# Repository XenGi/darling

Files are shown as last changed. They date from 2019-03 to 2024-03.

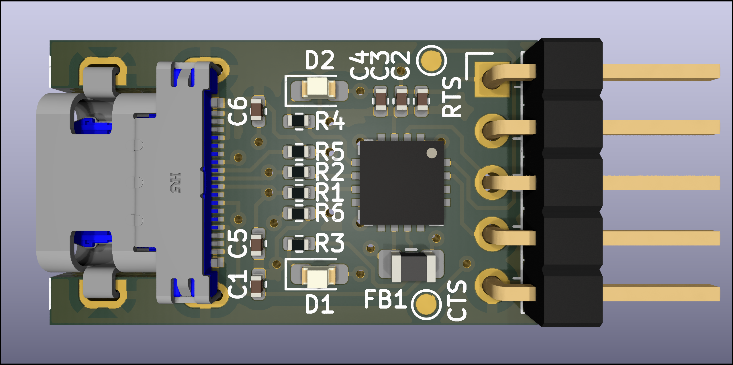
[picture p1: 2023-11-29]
darling_3d_front.png

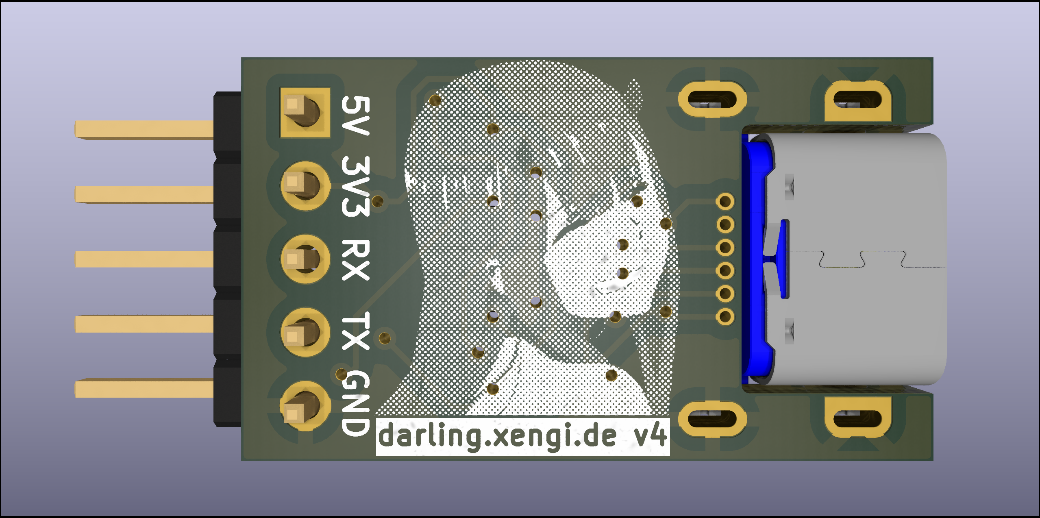
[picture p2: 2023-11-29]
darling_3d_back.png

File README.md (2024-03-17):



pcb
3d model front
3d model back

darling
=======

FTDI helper for the future. With FT230X, blinky lights and USB-C! Also potentially the tinyest USB-C to Serial adapter in the world. :smiley:

__Got a smaller USB-C to serial adapter? Please send me a link!__

BOM
---

| Part | Qty | Pkg | Ref | Description | Mouser | LCSC |
| --- | - | ----- | --- | --- | --- | ---- |
| Hirose CX70M-24P1 | 1 | - | J1 | USB-C Receptacle  | [798-CX70M-24P1](https://eu.mouser.com/ProductDetail/Hirose-Connector/CX70M-24P1?qs=NniTrqY%252BJ%252BUR9QssvRGPwA%3D%3D) | [C778726](https://www.lcsc.com/product-detail/C778726.html) |
| - | 1 | - | J2 | Pin Header | [571-826947-5](https://eu.mouser.com/ProductDetail/TE-Connectivity/826947-5?qs=xF5SkmKSM76JMcUnQ8djKQ%3D%3D) | [C6332198](https://www.lcsc.com/product-detail/C6332198) |
| FTDI FT230XQ-R | 1 | QFN16 | U1 | USB-Serial IC | [895-FT230XQ-R](https://eu.mouser.com/ProductDetail/FTDI/FT230XQ-R?qs=Gp1Yz1mis3VvmXwyDmIHOg%3D%3D) | [C128629](https://www.lcsc.com/product-detail/C128629) |
| - | 1 | 0603  | D1 | Red RX LED | [710-150060GS75000](https://eu.mouser.com/ProductDetail/Wurth-Elektronik/150060GS75000?qs=LlUlMxKIyB0UYkq5lDO8nA%3D%3D) | [C965804](https://www.lcsc.com/product-detail/C965804) |
| - | 1 | 0603  | D2 | Green TX LED | [710-150060RS75000](https://eu.mouser.com/ProductDetail/Wurth-Elektronik/150060RS75000?qs=LlUlMxKIyB3QnmZ3fw%2FVCA%3D%3D) | [C965799](https://www.lcsc.com/product-detail/C965799) |
| - | 2 | 0402  | R1, R2 | 27 Ohm Resistor | [652-CR0402FX-27R0GLF](https://eu.mouser.com/ProductDetail/Bourns/CR0402-FX-27R0GLF?qs=SFHnMgm9IsxG%252BvpJZf0h2g%3D%3D) | [C138021](https://www.lcsc.com/product-detail/C138021) |
| - | 2 | 0402  | R3, R4 | 270 Ohm Resistor  | [652-CR0402FX-2700GLF](https://eu.mouser.com/ProductDetail/Bourns/CR0402-FX-2700GLF?qs=SFHnMgm9IsyXrY3JqhOnHQ%3D%3D) | [C163474](https://www.lcsc.com/product-detail/C163474) |
| - | 2 | 0402  | R5, R6 | 5.1 kOhm Resistor | [652-CR0402FX-5101GLF](https://eu.mouser.com/ProductDetail/Bourns/CR0402-FX-5101GLF?qs=ePR1ZvdkOKImkuXR%2F%2FtvtA%3D%3D) | [C105873](https://www.lcsc.com/product-detail/C105873) |
| - | 1 | 0402  | C1 | 10 nF Capacitor | [80-C0402C103K3R7867](https://eu.mouser.com/ProductDetail/KEMET/C0402C103K3RAC7867?qs=2QcrrtqkWlmbWpEppaNgjw%3D%3D) | [C272878](https://www.lcsc.com/product-detail/C272878) |
| - | 2 | 0402  | C2, C4 | 100 nF Capacitor  | [81-GRM155C71H104JE9J](https://eu.mouser.com/ProductDetail/Murata-Electronics/GRM155C71H104JE19J?qs=QzBtWTOodeUR0Y4f0k0Zww%3D%3D) | [C541464](https://www.lcsc.com/product-detail/C541464) |
| - | 1 | 0402  | C3 | 4.7 uF Capacitor  | [81-GRM15C61E475ME15J](https://eu.mouser.com/ProductDetail/Murata-Electronics/GRM155C61E475ME15J?qs=By6Nw2ByBD02p8xq06vhEQ%3D%3D) | [C368809](https://www.lcsc.com/product-detail/C368809) |
| - | 2 | 0402  | C5, C6 | 47 pF Capacitor | [81-GRT1555C1H470FA2D](https://eu.mouser.com/ProductDetail/Murata-Electronics/GRT1555C1H470FA02D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) | [C527009](https://www.lcsc.com/product-detail/C527009) |
| Laird MI0805K601R-10 | 1 | 0805  | FB1 | Ferrite Bead | [875-MI0805K601R-10](https://eu.mouser.com/ProductDetail/Laird-Performance-Materials/MI0805K601R-10?qs=bbdZqDPQhEXXIHxc191aOg%3D%3D) | [C21286](https://www.lcsc.com/product-detail/C21286) |

See [Octopart][octopart] for a detailed list with links.
With current prices this totals to ~4.50€ just for parts excluding costs for the PCB manufacturing. If you need a PCB, just ask. I have lots of them. :)

Schematics
----------

schematics

Create Gerber files
-------------------

Export the gerber and drill files from KiCAD to a subdir like `gerber`. To create a ZIP file with the needed gerber files for a PCB fab:

```
cd gerber
zip darling.zip *.gbr *.drl
```

I recommend [JLCPCB][jlcpcb]. It's the cheapest way to get the PCBs and they offer decent quality.
You can directly order it at [PCBWay][pcbway]. They've got some nice matte black PCBs!
If you want purple PCBs you can also use [OSHPark][oshpark].
If you want it faster and you're in Germany/EU I uploaded it to [Aisler][aisler] to.

[pcb top pcb bottom][oshpark]

---

_Made with :heart: and aliexpress_

[pcb]: https://gitlab.com/xengi/darling/raw/master/darling_pcb.png
[3d-front]: https://gitlab.com/xengi/darling/raw/master/darling_3d_front.png
[3d-back]: https://gitlab.com/xengi/darling/raw/master/darling_3d_back.png
[schema]: https://gitlab.com/xengi/darling/raw/master/darling_schema.png
[octopart]: https://octopart.com/bom-tool/4VikRkAe
[jlcpcb]: https://jlcpcb.com/
[pcbway]: https://www.pcbway.com/project/shareproject/Darling_Rev4_f9889cb6.html
[oshpark_darling_top]: https://644db4de3505c40a0444-327723bce298e3ff5813fb42baeefbaa.ssl.cf1.rackcdn.com/4cf1ffcfeee0332e9eda92195310da6b.png
[oshpark_darling_bottom]: https://644db4de3505c40a0444-327723bce298e3ff5813fb42baeefbaa.ssl.cf1.rackcdn.com/1f266f38a687f960f46bc39729592b03.png
[oshpark]: https://oshpark.com/shared_projects/s8UnAcGC
[aisler]: https://aisler.net/p/NFTQABKA

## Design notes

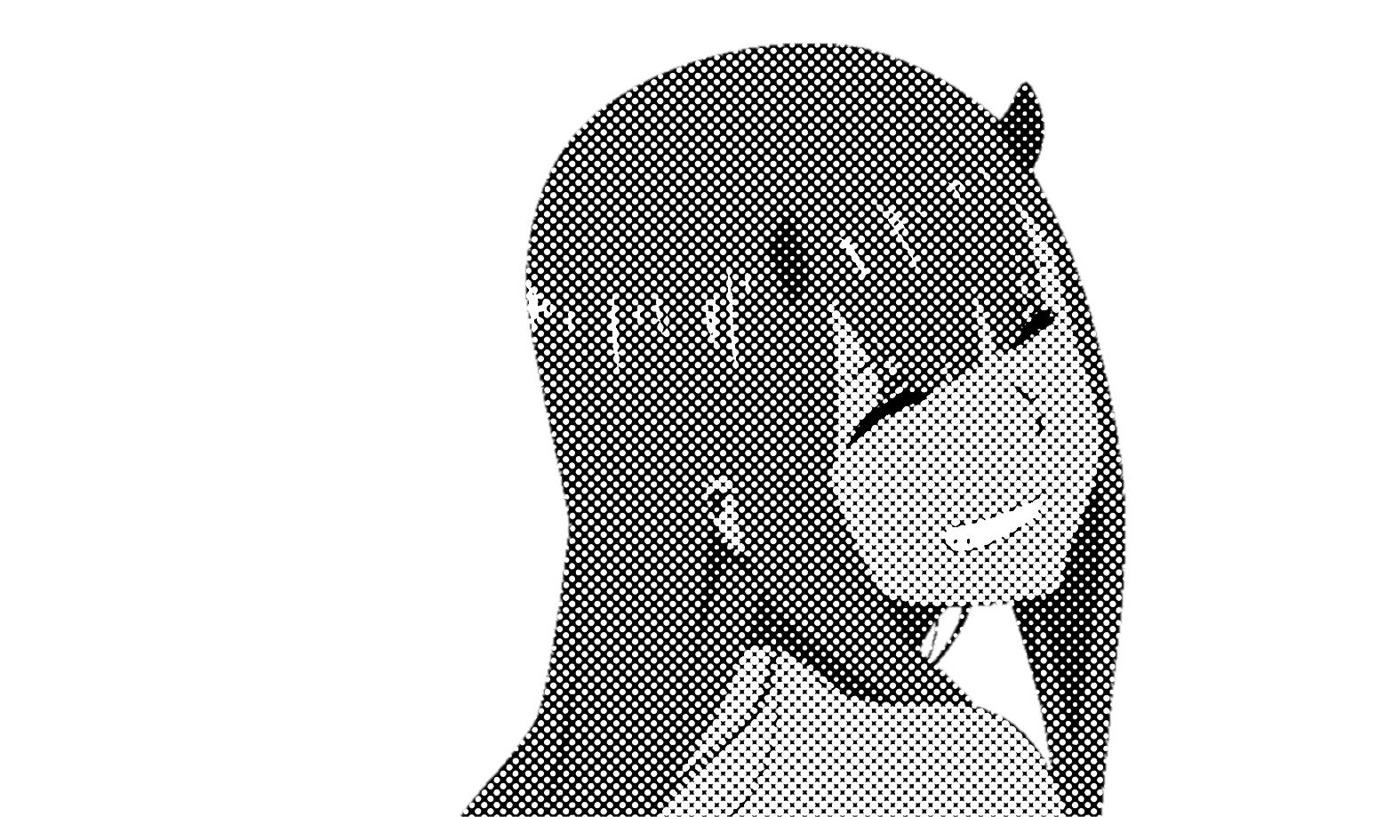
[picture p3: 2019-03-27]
preview_002.png

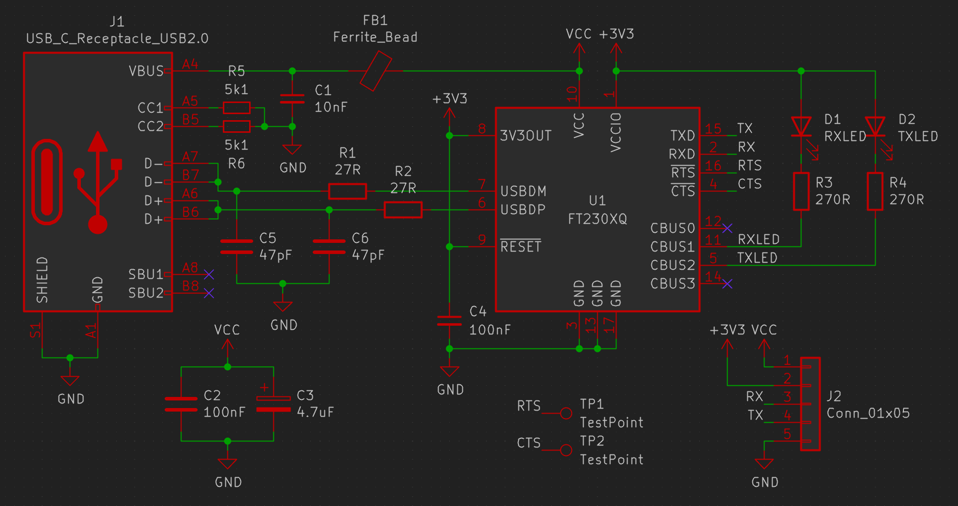
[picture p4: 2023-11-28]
darling_schema.png

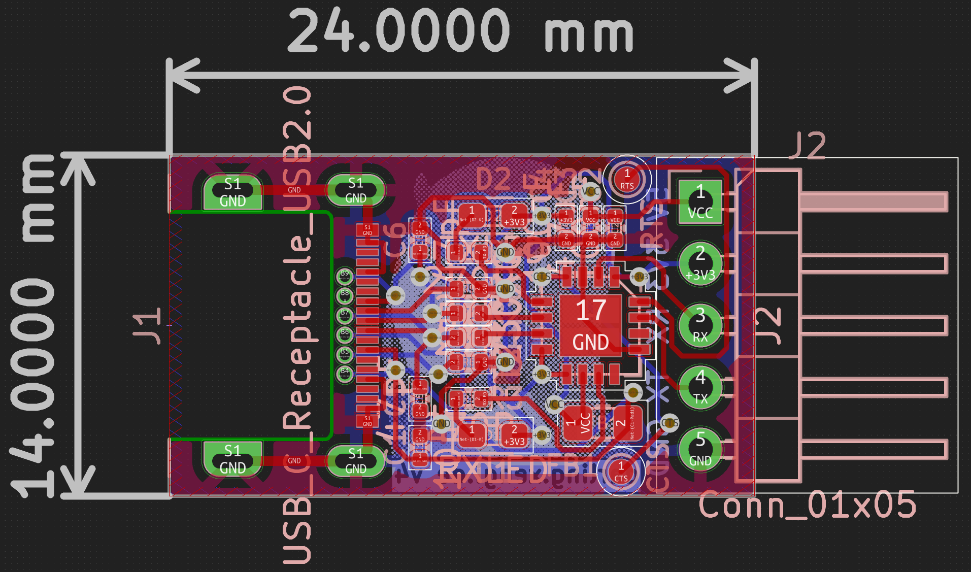
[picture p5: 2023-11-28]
darling_pcb.png

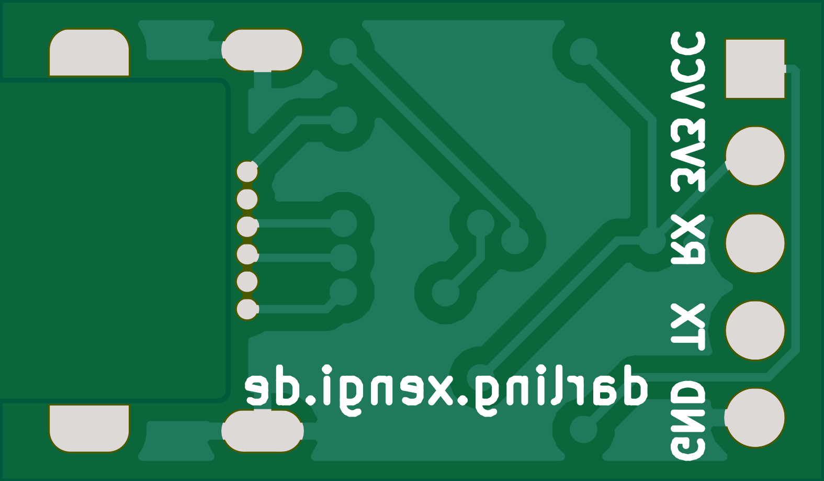
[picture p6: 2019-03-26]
preview.png

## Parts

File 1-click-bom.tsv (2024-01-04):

References | Qty | LCSC | Mouser
C1 | 1 | C272878 | 80-C0402C103K3R7867
C2 | 1 | C541464 | 81-GRM155C71H104JE9J
C3 | 1 | C368809 | 81-GRM15C61E475ME15J
C4 | 1 | C541464 | 81-GRM155C71H104JE9J
C5, C6 | 2 | C527009 | 81-GRT1555C1H470FA2D
D1 | 1 | C965804 | 710-150060GS75000
D2 | 1 | C965799 | 710-150060RS75000
FB1 | 1 | C21286 | 875-MI0805K601R-10
J1 | 1 | C778726 | 798-CX70M-24P1
J2 | 1 | C6332198 | 571-826947-5
R1, R2 | 2 | C138021 | 652-CR0402FX-27R0GLF
R3, R4 | 2 | C163474 | 652-CR0402FX-2700GLF
R5, R6 | 2 | C105873 | 652-CR0402FX-5101GLF
U1 | 1 | C128629 | 895-FT230XQ-R

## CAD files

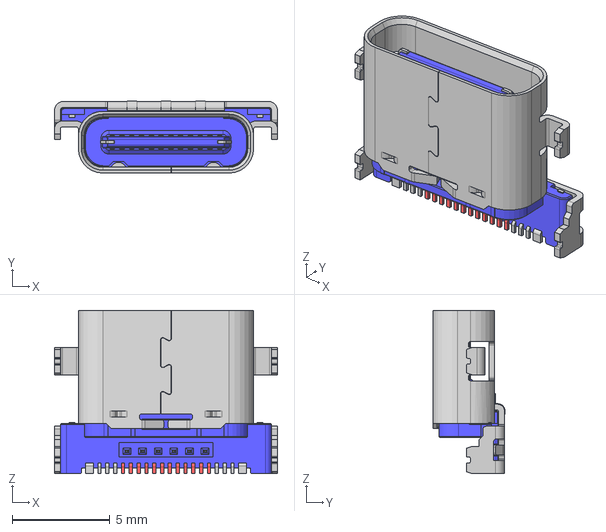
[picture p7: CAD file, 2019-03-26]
CX_4800304000.stp
11.4 x 3.69 x 8.35 mm

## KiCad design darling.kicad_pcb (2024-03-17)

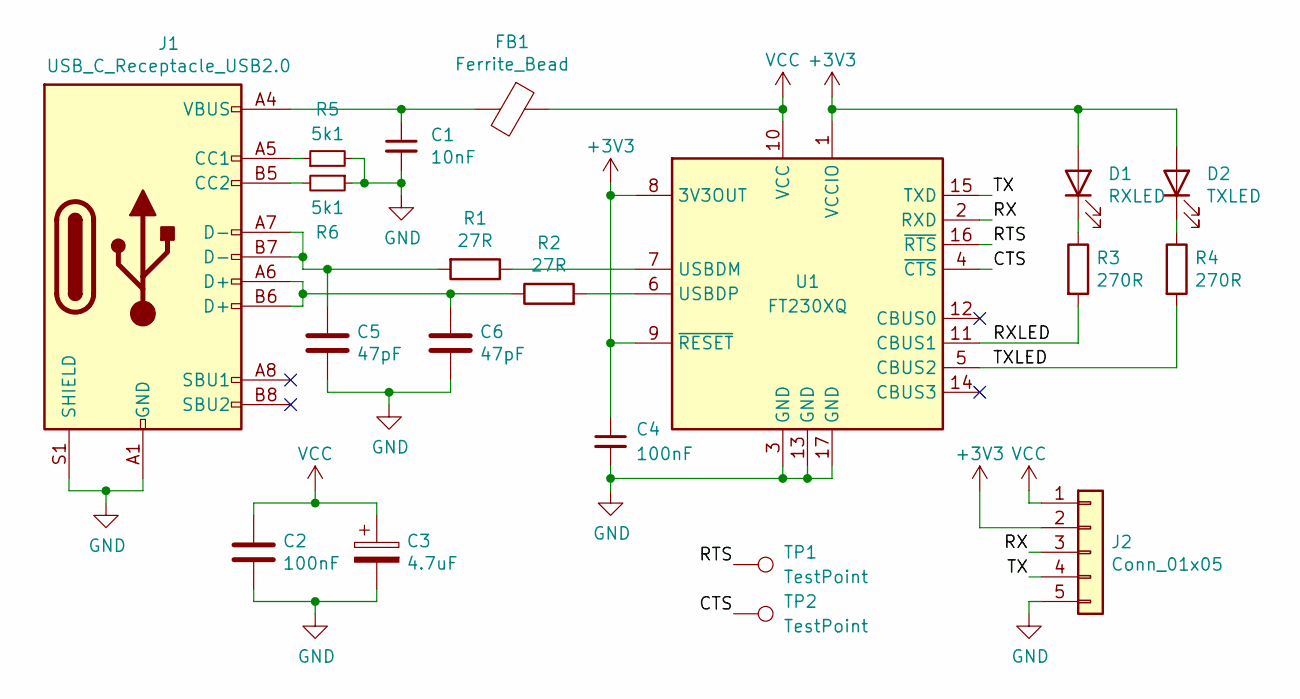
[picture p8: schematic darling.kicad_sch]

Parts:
C1: 10nF; C_0402_1005Metric; LCSC C272878
C2, C4: 100nF; C_0402_1005Metric; LCSC C541464
C3: 4.7uF; C_0402_1005Metric; LCSC C368809
C5, C6: 47pF; C_0402_1005Metric; LCSC C527009
D1: RXLED; LED_0603_1608Metric_Pad1.05x0.95mm_HandSolder; LCSC C965804
D2: TXLED; LED_0603_1608Metric_Pad1.05x0.95mm_HandSolder; LCSC C965799
FB1: Ferrite_Bead; L_0805_2012Metric_Pad1.15x1.40mm_HandSolder; LCSC C21286
J1: USB_C_Receptacle_USB2.0; CX70M-24P1; LCSC C778726
J2: Conn_01x05; PinHeader_1x05_P2.54mm_Horizontal; LCSC C6332198
R1, R2: 27R; R_0402_1005Metric; LCSC C138021
R3, R4: 270R; R_0402_1005Metric; LCSC C163474
R5, R6: 5k1; R_0402_1005Metric; LCSC C105873
TP1, TP2: TestPoint; TestPoint_Pad_D1.0mm
U1: FT230XQ; QFN-16-1EP_4x4mm_P0.65mm_EP2.5x2.5mm; LCSC C128629

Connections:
+3V3: C4.1, D1.2 (A), D2.2 (A), J2.2, U1.1 (VCCIO), U1.8 (3V3OUT), U1.9 (~RESET)
/CTS: TP2.1, U1.4 (~CTS)
/RTS: TP1.1, U1.16 (~RTS)
/RX: J2.3, U1.2 (RXD)
/RXLED: R3.2, U1.11 (CBUS1)
/TX: J2.4, U1.15 (TXD)
/TXLED: R4.2, U1.5 (CBUS2)
GND: C1.2, C2.2, C3.2, C4.2, C5.2, C6.2, J1.A1 (GND), J1.A12 (GND), J1.B1 (GND), J1.B12 (GND), J1.S1 (SHIELD), J2.5, R5.2, R6.1, U1.3 (GND), U1.13 (GND), U1.17 (GND)
unnamed: C1.1, FB1.2, J1.A4 (VBUS), J1.A9 (VBUS), J1.B4 (VBUS), J1.B9 (VBUS)
unnamed: C5.1, J1.A7 (D-), J1.B7 (D-), R1.2
unnamed: C6.1, J1.A6 (D+), J1.B6 (D+), R2.1
unnamed: D1.1 (K), R3.1
unnamed: D2.1 (K), R4.1
unnamed: J1.A5 (CC1), R5.1
unnamed: J1.B5 (CC2), R6.2
unnamed: R1.1, U1.7 (USBDM)
unnamed: R2.2, U1.6 (USBDP)
VCC: C2.1, C3.1, FB1.1, J2.1, U1.10 (VCC)

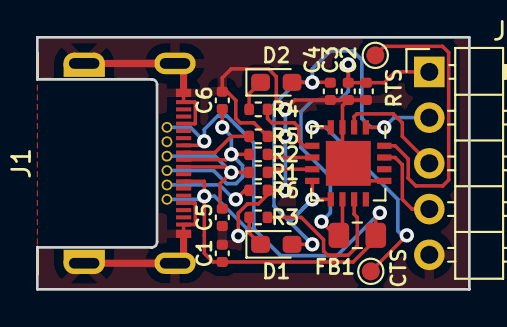
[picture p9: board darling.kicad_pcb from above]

Board: 2 copper layers, 24.0 x 14.0 mm, 20 parts (0 on the bottom side), 18 nets.

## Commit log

2018-06-17 finished design
    [sellerie3000.kicad_pcb, sellerie3000.sch]
2018-06-24 wow much update many unfinished
    [sellerie3000.kicad_pcb, sellerie3000.sch]
2018-06-25 nearly done
    [sellerie3000.kicad_pcb]
2018-06-25 measurements added
    [sellerie3000.kicad_pcb]
2019-03-26 refactured to version 2; new usb receptacle; even tinier
    [CX_4800304000.stp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]
2019-03-26 begone! strange repo!
    [darling-B.Cu.gbr, darling-B.Mask.gbr, darling-B.Paste.gbr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]
2019-03-27 artwork improved
    [darling-B.Cu.gbr, darling-B.Mask.gbr, darling-B.Paste.gbr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]
2019-04-19 switched LEDs
2019-04-20 reroute some parts
    [darling.kicad_pcb]
2019-04-20 fixed #4 usb-c is now reversable
    [darling.kicad_pcb, darling.sch]
2019-04-20 images updates
    [darling.sch]
2019-04-20 removed J1 label
    [darling.kicad_pcb]
2019-04-20 something changed
    [darling.kicad_pcb]
2019-04-20 drc runs again. woop woop!
    [darling.kicad_pcb]
2019-04-20 added updated gerber files
    [darling-B.Cu.gbr, darling-B.Mask.gbr, darling-B.Paste.gbr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]
2019-05-02 bom added in tsv format
    [bom.tsv]
2019-05-02 mouser ids added
    [bom.tsv]
2019-05-02 bom fixed
    [bom.tsv]
2019-05-02 aisler added to readme; bom updated
    [bom.tsv]
2023-07-10 Add missing CC resistors
    [darling.kicad_pcb, darling.kicad_sch, darling.sch]
2023-07-10 update pictures
    [darling.kicad_pcb, darling.kicad_sch]
2023-11-28 minimal touches
    [darling.kicad_pcb, darling.kicad_sch]
2023-11-28 PCB finalized
    [darling.kicad_pcb]
2023-11-28 final rev 4
    [darling-B.Cu.gbr, darling-B.Mask.gbr, darling-B.Paste.gbr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]
2023-11-28 update readme and images
    [darling.kicad_pcb, darling.kicad_sch]
2024-01-04 add LCSC and Mouser part numbers
    [bom.tsv, darling.kicad_pcb, darling.kicad_sch]
2024-01-04 update kitspace
    [1-click-bom.tsv]
2024-01-04 update pin header
    [1-click-bom.tsv, darling.kicad_sch]
2024-03-17 convert to kicad 8 format
    [darling.kicad_pcb, darling.kicad_sch]
2024-03-17 add pcbway link
